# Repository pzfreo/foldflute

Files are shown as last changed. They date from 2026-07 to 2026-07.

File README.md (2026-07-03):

# foldflute

Folded low-D whistle design notes and tooling.

## MCP Setup

This project uses `build123d-mcp` as an AI/MCP server via `uv tool run`; it is
not vendored or tracked as a submodule.

Project-scoped MCP config lives in `.mcp.json` and runs:

```sh
uv tool run --python 3.12 \
  --with openwind \
  --with scipy \
  build123d-mcp@latest \
  --allow-imports openwind,scipy,numpy
```

Openwind and SciPy are included for the acoustic helper workflow described in
`SPEC.md`.

## Layout

- `spec/` — InstrumentSpec JSONC documents (seed spec from SPEC.md §5)
- `foldflute/prelude.py` — acoustic engine, hole optimizer, bend corrections,
  fold-path solver; written to run inside the build123d-mcp `execute()`
  sandbox (load the spec host-side, inject as a dict)
- `scripts/` — parametric CAD builds for the solved designs + raw session log
- `reports/` — REPORT.md (first end-to-end run), solved specs, renders
- `artifacts/` — gated STL/STEP exports (M1 straight, M2 folded)

See `reports/REPORT.md` for the current design state: both M1 (straight) and
M2 (folded foot U-bend) are solved and export print-ready parts; the low A
hole layout is formally infeasible and was relaxed per the spec policy.

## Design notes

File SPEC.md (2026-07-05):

# foldflute - Folded Low-D Whistle Designer

**Project specification - draft v0.3 - 2026-07-03**  
**Owner:** Paul Fremantle

## 1. Overview

foldflute is a single-user desktop toolchain for designing a **folded-bore low D
tin whistle body** that:

- sounds as a low D whistle, with D4 as the fundamental;
- uses **standard six-hole tin whistle fingerings**;
- reuses an existing, known-good whistle headjoint for the windway, window, blade,
  and voicing-critical geometry;
- has the **physical length and approximate finger-hole layout of a low A
  whistle body** supplied by the user.

The bore is folded so that acoustic hole positions along the air column can land
near low A-style exterior finger positions. The acoustic target remains low D;
"low A body size" means physical length and hand layout, not a low A pitch
target.

An LLM orchestrates the design loop through `build123d-mcp` as the primary CAD
workbench: it builds geometry incrementally, renders views, measures dimensions,
checks clearances, compares shape revisions, exports artifacts, and runs
printability analysis. Deterministic solvers own the acoustically critical
numbers: bore length, tonehole positions, tonehole diameters, bend corrections,
chimney lengths, and printability checks.

**Core architectural insight:** the passive pitch model depends on the 1D air
column: bore radius vs. acoustic arc length, side-hole geometry, radiation
conditions, and boundary corrections. The exterior 3D body shape is mostly
acoustically free, provided the CAD-derived chimney depths and bend corrections
are fed back into the acoustic model.

## 1a. Requirement amendment — v0.4 (owner, 2026-07-05)

The low A physical layout goals are **withdrawn**. `physical_layout`
hole-position targets and the low A body-length target no longer constrain
the design. The binding ergonomic requirement is:

- **Adjacent holes within each hand are <= 29.0 mm centre to centre**
  (h1-h2, h2-h3 for the left hand; h4-h5, h5-h6 for the right hand).
- The fipple-to-left-hand distance and the left-hand-to-right-hand distance
  are unconstrained.

Consequences: G4 and the fold-path/layout machinery become optional
(compactness may still motivate folding, but nothing requires it); the
between-hands gap floats to whatever acoustics prefers; body length floats.

## 2. Goals

- G1. Produce a low D whistle body for an existing fixed headjoint.
- G2. Preserve standard six-hole tin whistle fingerings for the D major scale.
- G3. Predict resonance tuning before printing, accurate enough that one
  calibration print should suffice: relative tuning within +/-15 cents before
  calibration and +/-10 cents after one calibration iteration.
- G4. Fold the bore so acoustic hole positions map as closely as possible to a
  user-supplied low A physical layout: overall body length and approximate
  exterior hole/finger positions.
- G5. Wrap the air column in a printable body, with verified wall thickness,
  clearances, drainage, split-shell features, Augura printability analysis, and
  STL export.
- G6. Keep the full loop drivable by an LLM through `build123d-mcp`, using MCP
  tools for normal CAD iteration as well as final verification, while enforcing
  invariants in deterministic helper code.

## 3. Non-goals

- **Headjoint or voicing design.** Windway height, window length, blade geometry,
  chamfers, ramp shape, and mouthpiece ergonomics are copied from the existing
  headjoint and are not optimized.
- **Changing whistle fingering semantics.** v1 targets the standard D whistle
  six-hole diatonic chart. Chromatic half-holing and alternate cross-fingerings
  may be recorded later, but they are not optimized in v1.
- **Transverse flutes or reed instruments.** This project is for fipple whistles.
- **Sound synthesis or playability simulation.** We predict passive resonances,
  not tone, chiff, breath curve, or response.
- **Hosted, multi-user, or cloud service concerns.** This is a local desktop
  workflow.

## 4. System Architecture

```
                 +------------------------------+
                 | InstrumentSpec (JSONC)       |  single source of truth
                 +------+-----------+-----------+
                        |           |
          unrolled 1D   |           |  folded centerline + body params
                        v           v
      +----------------------+   +--------------------------+
      | Acoustic engine       |   | Geometry engine           |
      | (openwind helpers in  |   | (build123d via MCP)       |
      |  the CAD session)     |   |                          |
      | - impedance minima    |   | - folded bore sweep       |
      | - cents per fingering |   | - headjoint interface     |
      | - hole optimizer      |   | - tonehole chimneys       |
      | - bend corrections    |   | - shell split/export      |
      +----------+-----------+   | - clearance checks        |
                 |               | - Augura printability     |
                 |               +------------+-------------+
                 | measured chimney depths                 |
                 v                                         v
      +----------------------+   +--------------------------+
      | Fold-path solver      |   | Calibration protocol      |
      | (scipy constraints    |   | (print -> tuner -> fit    |
      |  + low A layout fit)  |   |  correction -> reprint)   |
      +----------+-----------+   +--------------------------+
                 ^
                 |
        +--------+---------+
        | LLM + human      | proposes topology/body shape,
        +------------------+ reads cents tables, drives iteration
```

### Division of Labour

| Concern | Owner |
|---|---|
| Headjoint/windway/voicing geometry | Existing physical headjoint |
| Standard whistle fingering chart | Spec, fixed in v1 |
| Hole positions, diameters, acoustic corrections | Acoustic optimizer |
| Fold path meeting low A length and finger layout | Fold-path solver |
| Exterior body aesthetics and fold topology choices | LLM + human, iterated in build123d-mcp |
| Incremental CAD modeling, measuring, rendering, export | LLM using build123d-mcp |
| Chimney depths, clearances, split shell, STL | Geometry engine through build123d-mcp |
| Final say on tuning and speaking quality | Human with tuner |

## 5. Data Model - `InstrumentSpec`

One JSONC document, with a Python dataclass mirror. All spec lengths are in
millimetres unless the field name says otherwise. Frequencies are in Hz. The
Openwind adapter converts to SI units at the boundary.

The acoustic arc-length origin is the headjoint window datum. The printable body
usually starts downstream at the headjoint socket. Therefore the full acoustic
bore length is:

```
headjoint.window_to_body_socket + body_centerline.arc_length
```

### Example Seed Spec

This example is intentionally a seed, not a final solved instrument. The user
must measure the existing headjoint and the low A reference body length/hole
layout before M1.

```jsonc
{
  "name": "low-d-folded-whistle-v1",
  "target": {
    "instrument": "low_d_tin_whistle",
    "fundamental": "D4",
    "fundamental_hz": 293.66,
    "pitch_standard_hz": 440.0,
    "temperament": "equal",
    "required_notes": [
      "D4", "E4", "F#4", "G4", "A4", "B4", "C#5", "D5",
      "E5", "F#5", "G5", "A5", "B5", "C#6", "D6"
    ]
  },

  "headjoint": {
    "reference": "reference-headjoints/user-low-d-headjoint-v1.step",
    "fixed": true,
    "acoustic_origin": "window_center",
    "measurements_confirmed": true,
    "tube_outer_diameter": 25.0,
    "tube_inner_diameter": 22.0,
    "tube_inner_radius": 11.0,
    "window_to_tube_end": 120.0,
    "sleeve_extension_beyond_tube_end": 56.0,
    "sleeve_end_from_window": 176.0,
    "sleeve_inner_diameter": 25.0,
    "sleeve_outer_diameter": 28.6,
    "sleeve_fit_clearance_radial": 0.1,
    "sleeve_fit_clearance_diametral": 0.2,
    "printed_body_mating_outer_diameter": 24.8,
    "body_connection": "printed_body_outer_diameter_slips_into_25mm_id_sleeve",
    "window_to_body_socket": 120.0,
    "socket_outer_diameter": 25.0,
    "socket_inner_radius": 11.0,
    "socket_depth": null,
    "nominal_insertion_depth": null,
    "effective_length_correction": 0.0,
    "notes": "Measured from the existing physical headjoint. The printed body acoustic start is at the 120 mm tube end; the 56 mm sleeve is mechanical overlap/retention rather than extra acoustic bore. CAD must not modify voicing geometry."
  },

  "bore": {
    "profile": [
      [0.0, 11.0],
      [120.0, 11.0],
      [590.0, 11.0]
    ],
    "cross_section": "circular",
    "prototype_bore_choice": "cylindrical",
    "body_start_arc": 120.0
  },

  "centerline": {
    "description": "Folded path for the printable body only. It starts at body_start_arc.",
    "segments": [
      {"type": "straight", "length": 172.168},
      {"type": "bend", "angle_deg": 180.0, "radius": 40.0},
      {"type": "straight", "length": 172.168}
    ]
  },

  "holes": [
    {
      "id": "h1",
      "label": "top",
      "finger": "L1",
      "position": null,
      "position_seed": 275.0,
      "diameter": null,
      "diameter_seed": 8.0,
      "position_bounds": [210.0, 340.0],
      "diameter_bounds": [5.5, 11.5],
      "chimney_height_estimate": 3.0,
      "chimney_height_measured": null,
      "exit_normal": [0.0, 0.0, 1.0]
    },
    {
      "id": "h2",
      "label": "second",
      "finger": "L2",
      "position": null,
      "position_seed": 325.0,
      "diameter": null,
      "diameter_seed": 8.0,
      "position_bounds": [260.0, 390.0],
      "diameter_bounds": [5.5, 11.5],
      "chimney_height_estimate": 3.0,
      "chimney_height_measured": null,
      "exit_normal": [0.0, 0.0, 1.0]
    },
    {
      "id": "h3",
      "label": "third",
      "finger": "L3",
      "position": null,
      "position_seed": 380.0,
      "diameter": null,
      "diameter_seed": 8.0,
      "position_bounds": [310.0, 445.0],
      "diameter_bounds": [5.5, 11.5],
      "chimney_height_estimate": 3.0,
      "chimney_height_measured": null,
      "exit_normal": [0.0, 0.0, 1.0]
    },
    {
      "id": "h4",
      "label": "fourth",
      "finger": "R1",
      "position": null,
      "position_seed": 425.0,
      "diameter": null,
      "diameter_seed": 8.0,
      "position_bounds": [360.0, 500.0],
      "diameter_bounds": [5.5, 12.0],
      "chimney_height_estimate": 3.0,
      "chimney_height_measured": null,
      "exit_normal": [0.0, 0.0, 1.0]
    },
    {
      "id": "h5",
      "label": "fifth",
      "finger": "R2",
      "position": null,
      "position_seed": 475.0,
      "diameter": null,
      "diameter_seed": 8.5,
      "position_bounds": [405.0, 545.0],
      "diameter_bounds": [5.5, 12.5],
      "chimney_height_estimate": 3.0,
      "chimney_height_measured": null,
      "exit_normal": [0.0, 0.0, 1.0]
    },
    {
      "id": "h6",
      "label": "bottom",
      "finger": "R3",
      "position": null,
      "position_seed": 525.0,
      "diameter": null,
      "diameter_seed": 9.0,
      "position_bounds": [455.0, 575.0],
      "diameter_bounds": [5.5, 13.0],
      "chimney_height_estimate": 3.0,
      "chimney_height_measured": null,
      "exit_normal": [0.0, 0.0, 1.0]
    }
  ],

  "fingering_scope": "standard six-hole tin-whistle diatonic fingerings, sounding D -> D' -> D''",
  "fingerings": [
    {"note": "D4",  "register": 1, "holes": {"h1": "closed", "h2": "closed", "h3": "closed", "h4": "closed", "h5": "closed", "h6": "closed"}},
    {"note": "E4",  "register": 1, "holes": {"h1": "closed", "h2": "closed", "h3": "closed", "h4": "closed", "h5": "closed", "h6": "open"}},
    {"note": "F#4", "register": 1, "holes": {"h1": "closed", "h2": "closed", "h3": "closed", "h4": "closed", "h5": "open",   "h6": "open"}},
    {"note": "G4",  "register": 1, "holes": {"h1": "closed", "h2": "closed", "h3": "closed", "h4": "open",   "h5": "open",   "h6": "open"}},
    {"note": "A4",  "register": 1, "holes": {"h1": "closed", "h2": "closed", "h3": "open",   "h4": "open",   "h5": "open",   "h6": "open"}},
    {"note": "B4",  "register": 1, "holes": {"h1": "closed", "h2": "open",   "h3": "open",   "h4": "open",   "h5": "open",   "h6": "open"}},
    {"note": "C#5", "register": 1, "holes": {"h1": "open",   "h2": "open",   "h3": "open",   "h4": "open",   "h5": "open",   "h6": "open"}},
    {"note": "D5",  "register": 2, "holes": {"h1": "closed", "h2": "closed", "h3": "closed", "h4": "closed", "h5": "closed", "h6": "closed"}},
    {"note": "E5",  "register": 2, "holes": {"h1": "closed", "h2": "closed", "h3": "closed", "h4": "closed", "h5": "closed", "h6": "open"}},
    {"note": "F#5", "register": 2, "holes": {"h1": "closed", "h2": "closed", "h3": "closed", "h4": "closed", "h5": "open",   "h6": "open"}},
    {"note": "G5",  "register": 2, "holes": {"h1": "closed", "h2": "closed", "h3": "closed", "h4": "open",   "h5": "open",   "h6": "open"}},
    {"note": "A5",  "register": 2, "holes": {"h1": "closed", "h2": "closed", "h3": "open",   "h4": "open",   "h5": "open",   "h6": "open"}},
    {"note": "B5",  "register": 2, "holes": {"h1": "closed", "h2": "open",   "h3": "open",   "h4": "open",   "h5": "open",   "h6": "open"}},
    {"note": "C#6", "register": 2, "holes": {"h1": "open",   "h2": "open",   "h3": "open",   "h4": "open",   "h5": "open",   "h6": "open"}},
    {"note": "D6",  "register": 3, "holes": {"h1": "closed", "h2": "closed", "h3": "closed", "h4": "closed", "h5": "closed", "h6": "closed"}}
  ],

  "physical_layout": {
    "reference": "mk-pro-a-web-derived",
    "source_url": "https://mkwhistles.com/products/mk-pro-low-a-whistle",
    "scale_drawing_url": "https://mkwhistles.com/cdn/shop/files/Pro_A_Scaling_Drawing_v2_7549fd57-1002-4cb1-be67-190358c345fa.pdf",
    "source_confidence": "approximate; derived from published scale drawing using its 20 mm calibration square",
    "meaning": "Physical A whistle body length and approximate finger-hole positions only; acoustics remain low D.",
    "coordinate_system": "x from body socket toward foot, y lateral, z outward from nominal front surface",
    "overall_reference_length": 386.0,
    "body_length": 286.4,
    "body_length_tolerance": 10.0,
    "non_acoustic_tail_allowed": false,
    "length_conflict_policy": "relax_visual_length",
    "max_width": null,
    "max_depth": null,
    "hole_centers_from_socket": {
      "h1": 91.3,
      "h2": 116.8,
      "h3": 143.3,
      "h4": 177.3,
      "h5": 197.3,
      "h6": 230.8
    },
    "hole_position_tolerance": 8.0
  },

  "ergonomics": {
    "finger_template_source": "measured_low_a_body_layout",
    "finger_template": {
      "h1": {"target_xyz": null, "surface_normal": [0.0, 0.0, 1.0], "tolerance": 4.0},
      "h2": {"target_xyz": null, "surface_normal": [0.0, 0.0, 1.0], "tolerance": 4.0},
      "h3": {"target_xyz": null, "surface_normal": [0.0, 0.0, 1.0], "tolerance": 4.0},
      "h4": {"target_xyz": null, "surface_normal": [0.0, 0.0, 1.0], "tolerance": 4.0},
      "h5": {"target_xyz": null, "surface_normal": [0.0, 0.0, 1.0], "tolerance": 4.0},
      "h6": {"target_xyz": null, "surface_normal": [0.0, 0.0, 1.0], "tolerance": 4.0}
    }
  },

  "body": {
    "style_prompt": "low A-sized folded low D whistle body",
    "min_wall": 2.0,
    "shell_split_plane": "bore_plane",
    "split_strategy": "design_split_from_start_with_single_canonical_solid",
    "shell_join": "glued_centerline_seam",
    "gasket": false,
    "alignment_features": true
  },

  "fabrication": {
    "process": "FDM",
    "material": "PETG",
    "print_bed": [256.0, 256.0],
    "max_exported_part_footprint": [250.0, 250.0],
    "layer_orientation": "split halves printed from the centreline split layout, subject to CAD printability checks",
    "shell_closure": "glued_down_centreline",
    "gasket_material": null,
    "headjoint_fit": "push_fit_printed_spigot_into_25mm_id_sleeve",
    "fallback_headjoint_seal": "waxed_thread_wrap_if_push_fit_leaks_or_slips",
    "printability": {
      "mcp_tool": "build123d-mcp.analyze_printability",
      "backend": "pzfreo/augura",
      "analysis_type": "BREP-exact FDM printability",
      "run_on": ["left_shell", "right_shell"],
      "build_volume": [256.0, 256.0, null],
      "bed_fit_margin": 3.0,
      "required_checks": [
        "watertight_manifold",
        "overhangs",
        "thin_walls",
        "minimum_vertical_feature",
        "tip_over_risk",
        "brim_or_raft_need",
        "bed_fit"
      ],
      "support_policy": "prefer redesign/orientation changes over supports inside toneholes, bore, socket, or glue lands"
    }
  },

  "calibration": {
    "temperature_c": 20.0,
    "global_length_correction": 0.0,
    "headjoint_effective_length_correction": 0.0,
    "hole_radius_corrections": {},
    "chimney_corrections": {},
    "observed_fingering_residuals_cents": {}
  }
}
```

### Invariants

- `bore.body_start_arc == headjoint.window_to_body_socket`.
- `centerline.arc_length == bore.profile[-1][0] - bore.body_start_arc` within
  0.25 mm. Bend segment arc length is `abs(angle_rad) * radius`.
- A loaded seed spec may have `holes[].position == null` and
  `holes[].diameter == null`; an optimized spec must not.
- Every optimized hole position must be greater than `bore.body_start_arc` and
  less than the final bore arc length.
- `chimney_height_estimate` may be used only before the first CAD build.
  `chimney_height_measured` must be written back from the actual CAD body before
  convergence is accepted.
- `fingerings` is the source of truth for which holes are open or closed for a
  target note. The LLM does not infer fingering masks from note names.
- The headjoint reference geometry is immutable. CAD tools may model sockets,
  adapters, or mating surfaces, but must not modify windway/window/blade
  geometry.
- `physical_layout` is a low A visual/ergonomic reference only. It must never
  change the target pitch from D4.
- A hole target is geometrically reachable only if the distance from the body
  socket to the target point is less than or equal to that hole's available
  acoustic body arc length, within tolerance:
  `distance(socket, target_xyz) <= hole.position - bore.body_start_arc + tolerance`.
  A fold can make an acoustic path longer than the straight-line distance, but it
  cannot make a point farther away than the arc length available to it.
- `physical_layout.non_acoustic_tail_allowed == false` for this draft. If low A
  visual length conflicts with low D acoustic reach, relax the visual length
  rather than adding a non-acoustic tail.

## 6. Acoustic Engine

Openwind runs in the same Python session as the build123d MCP work so the spec,
CAD-derived chimney depths, and acoustic helpers share one namespace. Use the
project `.mcp.json` to launch `build123d-mcp` via `uv tool run`. The effective
command should be equivalent to:

```
uv tool run --python 3.12 \
  --with openwind \
  --with scipy \
  build123d-mcp@latest \
  --allow-imports openwind,scipy,numpy
```

At session start, call the MCP `version` tool and confirm `build123d-mcp` and
`augura` are listed, then call `health_check`. Augura is the printability backend
used by `build123d-mcp.analyze_printability`; do not replace that gate with a
visual inspection or slicer screenshot.

If Openwind's transitive imports are blocked by the sandbox, use an OS-level
sandbox or local trusted environment and relax the Python import allowlist there.
Do not vendor Openwind into build123d-mcp.

### 6.1 LLM build123d-mcp Workflow

The LLM must use `build123d-mcp` as the normal CAD workbench, not only as a final
export tool. The expected loop for geometry work is:

1. Start each design session with `version`, `health_check`, and `session_state`.
   Confirm `build123d-mcp`, `augura`, and required CAD dependencies are available.
2. Build geometry incrementally with `execute`, keeping stable named parameters
   for all important dimensions: bore radius, bend radius, sleeve fit, wall
   thickness, split-plane offsets, glue-land dimensions, and print-bed limits.
3. Register important shapes with `show(..., name)`. At minimum use names for
   `air_solid`, `body_solid`, `left_shell`, `right_shell`, `headjoint_reference`
   or `headjoint_socket`, and each diagnostic clearance body if created.
4. After every meaningful boolean or sweep, call `measure` before relying on a
   render. Numeric checks are the first proof that the model changed correctly.
5. Use `render_view` for human and LLM visual review after `measure` confirms the
   object is plausible. Use clip planes to inspect bore continuity, toneholes,
   glue lands, and socket geometry.
6. Use `clearance`, `cross_sections`, `find_holes`, `resolve`, and
   `verify_spec` for hard geometric checks: adjacent bore passes, chimneys vs.
   bore passes, shell wall thickness, sleeve fit, and print-bed footprint.
7. Use `save_snapshot` before risky edits and `diff_snapshot` or
   `shape_compare` after changes that should affect only a local region.
8. Use `script` or an equivalent reproducible artifact before export. The final
   STL/STEP files must be reproducible from the saved script plus
   `InstrumentSpec`.
9. Use `export` only after hard checks pass: validity, dimensions, clearances,
   chimney write-back, and Augura printability.

The LLM may propose topology and body-shape changes, but it must not accept an
unmeasured visual impression as proof. Any unresolved MCP error, failed boolean,
unexpected topology count, or failed printability report sends the design back to
the relevant solver/CAD step.

Core functions in the foldflute prelude:

- `load_spec(data) -> InstrumentSpec` validates units, invariants, and the
  fingering chart.
- `to_openwind_geometry(spec, fingering) -> OpenwindInput` converts mm to metres,
  applies headjoint effective-length correction, applies bend corrections, and
  uses measured chimney heights when available.
- `analyze(spec) -> {note: {resonance_hz, cents_vs_target, mode_index}}`
  computes input impedance per fingering and reads the impedance **minima**
  relevant to open-open flute/whistle resonators.
- `optimize_holes(spec) -> spec` solves tonehole positions and diameters for the
  required standard fingerings. It uses Openwind inversion if the constraint set
  is expressible there; otherwise it falls back to scipy optimization around
  `analyze`.
- `apply_calibration(spec, observations) -> spec` fits physical corrections:
  global length, headjoint effective length, hole-radius offsets, and chimney
  offsets. Per-fingering cents residuals are stored for diagnostics, not used as
  the primary fitted variables.

### 6.2 Bend Correction Layer

Openwind has no native 3D bend model. The spec-to-openwind translation applies
published effective-length corrections for bent air columns per bend, as a
function of bend angle and radius/bore ratio. Corrections live in one cited module
so they can be refined against calibration data.

Loss and radiation defaults:

- viscothermal losses on;
- unflanged radiation at open toneholes and the foot;
- room temperature from `spec.calibration.temperature_c`;
- no undercutting model in v1.

## 7. Fold-Path Solver

Input:

- optimized acoustic hole positions and diameters from section 6;
- body centerline topology: fold count, segment order, bend angles, bend radii;
- low A physical layout: body length and approximate hole centers from the socket;
- optional width/depth envelope limits;
- per-hole target exterior point, tolerance, and preferred surface normal.

Output:

- centerline parameters such that each acoustic hole position exits the body
  within tolerance of its assigned low A-style finger target, where reachable;
- hole exit axes that are sealable by the assigned finger and do not intersect
  another bore pass;
- an infeasibility report if the requested topology cannot satisfy the constraints.

Method:

- constrained least squares over segment lengths, bend radii, bend orientations,
  and optional body pose;
- hard rejection for wall, clearance, bend-radius, and physical reachability
  violations;
- soft penalties for finger target error and deviation from preferred normals.

If infeasible, the solver reports which hole/finger/layout constraint failed. The
LLM changes topology or relaxes the low A visual layout; it does not add
non-acoustic tail length or hand-edit acoustic hole positions.

## 8. Geometry Engine and Verification

Build steps, all inside the `build123d-mcp` session and following the section
6.1 workflow:

1. Import or parametrically model the existing headjoint interface. Treat the
   voicing geometry as immutable reference.
2. Build one canonical folded body centerline beginning at `bore.body_start_arc`.
3. Sweep the circular bore along the centerline to create one canonical air solid.
4. Choose the centreline split plane, glue lands, alignment features, and print
   orientation before finalizing the exterior body.
5. Add socket/adapter geometry to mate with the existing headjoint.
6. Generate the exterior body to match the low A reference length and approximate
   hole layout where acoustically reachable.
7. Boolean-subtract the air solid.
8. Cut tonehole chimneys from bore wall to body surface at solved acoustic
   positions and solved exit normals.
9. Write back actual `chimney_height_measured` for every hole.
10. Register the two split shell solids as named MCP objects, conventionally
    `left_shell` and `right_shell`.
11. Run `analyze_printability` on each shell object using the Augura backend and
    store both the plain-text summary and JSON findings with the build artifacts.
12. Export the two split shells and a reproducible build script/artifact only
    after the Augura-backed printability gate passes.

Hard constraints:

- Bend radius >= 1.5x local bore diameter; 2x preferred.
- Folded body approximates the low A physical length within tolerance where
  compatible with low D acoustic reach. If length conflicts, relax visual length;
  do not add a non-acoustic tail in this draft.
- Hole exits are within tolerance of the low A reference positions, unless the
  solver has reported the exact low A location as geometrically unreachable and
  the layout has been relaxed.
- Wall between adjacent bore passes >= `body.min_wall`.
- No tonehole chimney intersects another bore pass.
- Glued centreline seam has continuous bonding land and enough access for clean
  assembly.
- Each exported shell fits inside the 256 mm x 256 mm print bed with margin;
  default maximum footprint is 250 mm x 250 mm.
- Headjoint socket fit has explicit tolerance and insertion stop. The baseline is
  push-fit into the 25 mm ID sleeve; waxed thread wrap is allowed as a fallback
  seal/retention method if the printed fit leaks or slips.
- `build123d-mcp.analyze_printability` passes on every shell, using Augura
  (`pzfreo/augura`) as the printability backend.
- No moisture trap: the lowest interior point in playing orientation drains
  toward an opening, or a drain feature is added.
- Textured or sculptural body details must not thin the wall below `min_wall`.

### 8.1 MCP / Augura Printability Protocol

Printability analysis is an MCP-driven hard gate, not a manual review. For every
candidate geometry:

1. Use `show(shell, "left_shell")` and `show(shell, "right_shell")` in
   `build123d-mcp` so each half is addressable by name.
2. Run `measure` on both shells to confirm non-zero volume, expected bounding
   boxes, and PETG material mass estimates.
3. Run `clearance` and local wall checks for bore-to-bore and chimney-to-bore
   spacing before printability analysis.
4. Run `analyze_printability` on `left_shell` and `right_shell`, with build
   volume set to the 256 mm x 256 mm bed and the default 250 mm x 250 mm maximum
   footprint margin from `spec.fabrication`.
5. Treat any Augura FAIL as design rejection. Preferred fixes are fold topology,
   shell split/orientation, glue land geometry, wall thickness, or local body
   shape changes. Do not accept supports inside the bore, toneholes, socket, or
   glue lands as a primary fix.
6. Store the Augura JSON report beside the STL/STEP exports and include the
   pass/fail summary in the build notes.

Required Augura-backed findings for each shell:

- watertight/manifold solid;
- overhangs compatible with the chosen FDM orientation, or explicitly redesigned;
- thin walls no thinner than `body.min_wall`;
- minimum vertical feature compatible with the intended layer height;
- tip-over/brim/raft risk acceptable for PETG on the selected bed;
- bed fit inside 256 mm x 256 mm, with exported footprint no larger than
  250 mm x 250 mm unless intentionally overridden in the spec.

## 9. LLM Orchestration

The LLM drives the loop through the `build123d-mcp` session. Deterministic
helpers enforce the invariants; the LLM proposes topology, low A layout
interpretation, and body aesthetics. Every geometry iteration should leave MCP
evidence: named session objects, measurements, renders or clipped renders,
clearance checks, snapshots/diffs where useful, and printability reports before
export.

1. Human supplies measured headjoint dimensions or a headjoint CAD/scan.
2. Human supplies the low A reference body length and approximate hole/finger
   positions.
3. LLM drafts `InstrumentSpec` with the standard whistle fingering chart.
4. `optimize_holes` solves acoustic positions and diameters.
5. Fold-path solver places those positions into the low A-style physical layout
   where reachable.
6. Geometry build in `build123d-mcp` writes back measured chimney depths.
7. `analyze_printability` runs through build123d-mcp/Augura on both shell
   objects; rejected geometry returns to topology/body/split design.
8. `analyze` reruns with measured chimney depths and bend corrections.
9. Iterate steps 4-8 until cents table, hole dimensions, chimney depths, and
   Augura printability reports are stable.
10. Render for human review, export STLs, print prototype.

The LLM never hand-adjusts hole positions, hole diameters, or bend corrections.
It changes topology, layout choices, body shape, or targets and reruns the
solvers.

## 10. Calibration Protocol

1. Glue the PETG split shells along the centreline seam and let the adhesive cure.
2. Assemble the existing headjoint with the printed prototype body at the nominal
   insertion depth using the sleeve push fit.
3. Leak-test the glued shell and sleeve joint: block all holes and the foot, then
   check for back-pressure. If the sleeve joint leaks or slips, wrap the mating
   spigot with waxed thread and repeat the leak test.
4. Record each required fingering with a tuner: three trials, moderate breath,
   stable headjoint insertion, temperature noted.
5. Fit physical corrections: global body length, headjoint effective length,
   hole-radius offsets, and chimney offsets.
6. Store observations and fitted corrections in `spec.calibration`.
7. Re-run optimizer and geometry, then reprint if corrections exceed tolerances.

Acceptance after one calibration iteration:

- D4 through D6 standard whistle fingerings within +/-10 cents at moderate breath;
- no hole requires uncomfortable half-covering for a required diatonic note;
- headjoint socket remains airtight and repeatable after disassembly/reassembly.

## 11. Milestones

- **M0 - Headjoint capture.** Measure the existing headjoint: socket dimensions,
  outlet bore radius, window-to-body-socket distance, nominal insertion depth,
  and source/provenance. Exit: reference CAD or parametric interface exists and
  the spec can validate against it.
- **M1 - Straight-body low D validation.** Print a straight low D body for the
  existing headjoint with standard whistle fingerings. Exit: toolchain runs
  end-to-end and relative tuning is within +/-15 cents before calibration.
- **M2 - Folded low D in low A physical layout.** Fold the same acoustic design
  so the exterior length and approximate hole positions follow the measured low A
  reference where reachable. Exit: folded version is within +/-10 cents of the
  straight sibling per required fingering after applying the same calibration.
- **M3 - Ergonomic shell.** Refine the exterior body and finger template for the
  target hand/body size. Exit: all required holes are reachable and sealable,
  and build123d-mcp/Augura printability checks pass for both split shells.
- **M4 - LLM end-to-end.** LLM drives measured brief -> solved spec -> validated
  print files. Exit: one printed folded low D whistle accepted by the human
  player.

## 12. Licensing

- build123d-mcp is Apache-2.0.
- Augura (`pzfreo/augura`) is Apache-2.0 and is used through
  `build123d-mcp.analyze_printability` for BREP-exact FDM printability analysis.
- Openwind is GPLv3 as distributed on PyPI at the time of this draft. Keep it as
  a user-installed optional runtime dependency, for example via `uv tool run
  --with openwind`, and do not make it a bundled dependency of build123d-mcp.
- foldflute imports Openwind in its acoustic helpers. If distributed, license
  foldflute GPL-compatibly or split the Openwind-dependent pieces into a
  separately licensed/private component.
- The existing headjoint CAD/scan must have clear provenance. If it is derived
  from a commercial whistle, keep it private unless permission is explicit.

## 13. Risks and Open Questions

| Risk | Mitigation |
|---|---|
| Existing headjoint effective length is unknown | M0/M1 straight-body calibration before any folded design |
| Headjoint speaks poorly with the solved bore diameter | Match body inlet radius to measured headjoint outlet; test straight body first |
| Fold bend corrections exceed model validity | Keep bend radius >= 2x bore diameter where the layout allows; compare M2 to M1 |
| Deep chimneys from sculptural body detune notes | CAD writes measured chimney heights back before acoustic convergence |
| Split-shell leaks alter tuning | Continuous centreline glue land, alignment features, adhesive cure time, and leak test before tuning measurement |
| Sleeve push fit leaks or slips | Target 24.8 mm printed spigot OD for 25 mm ID sleeve; add waxed thread wrap if needed |
| Augura rejects a shell for overhang, thin wall, bed fit, or tip-over risk | Change split orientation, body shape, glue lands, fold topology, or wall thickness; do not rely on supports inside acoustic or mating features |
| Low A hole targets are farther from the socket than low D acoustic arc length permits | Solver reports infeasible hole/finger pairs; relax the visual layout rather than adding non-acoustic tail length |
| PETG print material, temperature, or moisture drift | Record PETG brand, layer orientation, temperature, and headjoint insertion in calibration |

Open questions:

None for draft v0.3.

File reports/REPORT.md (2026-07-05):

# foldflute first end-to-end run — 2026-07-03

Toolchain run against SPEC.md draft v0.3, driven through `build123d-mcp`
(0.3.62, augura 0.1.5, openwind via `uv tool run`). Deliverables: solved M1
straight and M2 folded designs, gated print files in `artifacts/`, solver
sources in `foldflute/prelude.py`, parametric build scripts in `scripts/`.

## 1. Acoustic model

Openwind 1D FEM, viscothermal losses on, unflanged radiation at holes and
foot, 20 °C, impedance **minima** at the window datum (x=0), headjoint
effective-length correction 0.0 (to be calibrated in M1). Resonances located
by a local geometric frequency grid ±170 cents around each target with
two-stage parabolic refinement — openwind's phase-based
`antiresonance_frequencies()` was unreliable on coarse grids.

Hole positions and bore length are solved by Gauss–Seidel (bore end → D4,
then h6→h1 for E4…C#5) with damped secant steps; register 1 converges to
±0.1 cents in 2–3 sweeps. Register 2 and D6 are *predictions*, controlled by
the diameter choice, which is an input (see §2).

## 2. Diameter scenario study (straight bore)

| scenario | diameters h1..h6 | worst R2 note | h1–h6 span | fold-layout gain |
|---|---|---|---|---|
| S0 seed | 8/8/8/8/8.5/9 | C#6 −97 c | 209 mm | — |
| **S1 big (selected)** | 11/10.5/10/10/10.5/11 | C#6 −26 c | 205 mm | none |
| S2 compression | 11.5/11/10.5/8/7/6.5 | F#5 −37 c | 180 mm | ~25 mm |
| S3 compromise | 11.5/11/10.5/9.5/9/8.5 | C#6 −24 c | 194 mm | ~10 mm |

Selected S1: large holes buy ~70 cents on the top of register 2 (the
open-lattice cutoff moves up); diameter "compression" of the hole span costs
real register-2 accuracy and recovers only ~25 mm of the ~110 mm needed to
reach the low A layout. Passive-model caveat: players overblow the second
register slightly sharp, so the −10…−26 c predictions up high should play
closer than they read.

## 3. Solved designs

Both use S1 diameters, bore Ø22 cylindrical, chimneys 3.30 mm (measured from
the as-built CAD wall and written back per spec; the 3.0 mm estimate shifted
holes by ~1 mm, above the rebuild threshold, so geometry was rebuilt).

**M1 straight**: bore end 571.60 mm from window. Holes (mm from window):
283.6 / 319.3 / 358.9 / 411.1 / 431.9 / 488.3.

**M2 folded**: bore end 574.57 (+2.97 vs M1 — the bend correction re-solve),
bend start 464.90, h6 at 41.8° into the bend. Holes: 283.6 / 319.3 / 358.9 /
411.1 / 431.9 / 489.0.

Model cents (register 1 all ±0.4 c by construction):

| note | D4 | E4 | F#4 | G4 | A4 | B4 | C#5 | D5 | E5 | F#5 | G5 | A5 | B5 | C#6 | D6 |
|---|---|---|---|---|---|---|---|---|---|---|---|---|---|---|---|
| M1 | 0.0 | −0.1 | −0.2 | −0.1 | +0.4 | −0.4 | −0.1 | +7.7 | −2.1 | −9.5 | −6.7 | −17.7 | −23.0 | −25.8 | +13.1 |
| M2−M1 | 0.0 | 0.0 | 0.0 | 0.0 | 0.0 | 0.0 | 0.0 | 0.0 | 0.0 | 0.0 | 0.0 | 0.0 | 0.0 | 0.0 | 0.0 |

M2 matches M1 within 0.03 cents per fingering in-model (the M2 exit
criterion of ±10 c is then a test of the bend-correction model itself once
printed). G3's ±15 c pre-calibration target is met for register 1 + D5/E5/
F#5/G5/D6; A5/B5/C#6 sit at −18…−26 c passive.

## 4. Bend correction (SPEC 6.2)

Toroidal bend, long-wavelength limit, potential (1/r) flow across the
section: inertance ratio bend/straight = (1+√(1−B²))/2 ≈ 1−B²/4, B = bore
radius / bend radius. Same volume ⇒ compliance unchanged ⇒ the bend is
acoustically shorter than its arc by that fraction (pitch rises). Applied as
a piecewise arc-length remapping with κ=1 (velocity-antinode worst case;
κ is the calibration knob). For R=33/bore 11: 2.83% of the 103.7 mm bend arc
= 2.9 mm, ≈ +9 c on D4 — matching the observed +2.97 mm bore-end re-solve.
Refs: Nederveen JASA 104(3):1616 (1998); Félix, Dalmont, Nederveen JASA
131:4164 (2012). (Exact published coefficients are paywalled; the derivation
above is in `foldflute/prelude.py` and is calibration-refinable.)

## 5. Fold-path result — the honest news

With a Ø22 cylindrical bore, a 180° bend needs πR ≥ 104 mm of arc at the
minimum legal radius (1.5×bore Ø = 33 mm):

- between adjacent toneholes: < 57 mm available → impossible;
- above h1 (order-preserving fold-back = 2 bends ≥ 207 mm): ~80 mm of
  straight available below the 56 mm spigot → impossible;
- wholly below h6: ~90 mm of tail → impossible.

**The only legal fold is a foot U-bend with h6 partway into the bend**
(41.8°, 10.5 mm lateral offset — comparable to offset pinky holes on
flutes). Solved fold: R=33, passes 66 mm apart in-plane, visible body 338.5
mm vs low A target 286.4 (+52.1, relaxed per `relax_visual_length`); foot
opening returns up the second pass 6 mm from the bend apex (the low point —
condensate drains to the opening; no drain hole needed).

The low A hole layout itself is **infeasible for any fold topology**: hole
spacing on a single pass equals acoustic spacing (span ~205 mm vs low A's
139.5 mm), and diameter compression tops out ~25 mm (§2). Exterior errors vs
the MK Pro A targets: h1 +17, h2 +27, h3 +40, h4 +58, h5 +59, h6 +81 mm
(tolerance 8 mm). Per SPEC §7 the layout is relaxed rather than hand-editing
acoustics. Datum assumption: `hole_centers_from_socket` measured from where
the body emerges from the sleeve (arc 176); if the datum is the tube end
(arc 120), all errors grow by 56 mm — worth confirming against the MK
drawing.

A 4-pass "S above the holes + foot U" topology could hit the 286 mm length
but needs ≥207 mm folded above h1 where only ~80 mm exists, and would push
h1 above the socket. Options if the low A length matters more than v0.3's
constraints allow: taper/neck the foot bore (relaxes local bend-radius
floor), allow smaller top-fold radii, or accept a ~95 mm-wide 3-tube bundle
with bassoon-style hole ergonomics. Parked for discussion.

## 6. Print architecture and gates

| part | geometry | print | Augura |
|---|---|---|---|
| M2 section_a | x 0–172 + 20 tenon, carries h1, spigot Ø24.8 | vertical, monolithic | 4 warnings¹ |
| M2 left_shell (front) | +z half of section B; carries h2–h6 wholly (seam never crosses a hole) | seam face down | 2 warnings + 3 info |
| M2 right_shell (back) | −z half | seam face down | same |
| M2 alignment_pin ×3 | Ø2.3×4 loose dowels into Ø2.5 recesses in 3 seam bosses | standing | brim advisory |
| M1 section_a | x 0–219 + tenon, h1–h2 | vertical | 5 warnings¹ |
| M1 section_b | x 219–451.6, h3–h6, socket ring | vertical | 3 warnings¹ |

¹ All findings are warnings/info, no failures: (a) tenon/socket stop-ring
ceilings (1.3–2.1 mm ring bridges — left as-is, they are the insertion
stops); (b) tonehole ceilings on vertical prints (4.6–4.8 mm bridges —
routine, ream after printing if sagged); (c) brim recommended on tall
sections (aspect 15–19 — yes, use a brim); (d) 0.2–0.4 mm "thin wall" =
tangential feather edges where hole cylinders exit curved walls, inherent to
drilled toneholes. Augura reported no overhang findings on the Ø22 bore
crowns of the flat-printed shells; treat crown sag as a print-quality watch
item regardless.

Section A is deliberately monolithic (deviation from a whole-body shell
split): the two sealing surfaces — headjoint spigot and joint tenon — stay
seamless and round. Joints: tenon Ø26.0 into socket Ø26.2 (0.2 diametral,
same as the headjoint sleeve fit), 20 mm engagement, shoulder stop, waxed
thread fallback per spec.

All fit checks passed: tenon/socket touching with zero interpenetration,
shells touching on the full seam, air column touching walls with zero
intersection volume. All parts pass the CAD validity gate (watertight
manifold single solids). Footprints ≤ 227×101 mm (bed 256², limit 250²).

## 7. Session evidence

- `reports/solved_designs.json` — full solved specs + cents tables + fold report
- `reports/solver_run_summary.json` — scenario study + provenance
- `reports/m2_*.png` — renders (iso, assembly, clipped)
- `scripts/session_build_log.py` — raw executed-session log (provenance)
- `scripts/build_m*.py` — clean parametric rebuilds
- `artifacts/m1/`, `artifacts/m2/` — STLs (bed-oriented) + canonical STEPs

## 8a. Addendum — convoluted internal bore study (same day)

Clarified intent: the goal was never "shorten with a bend" but a **convoluted
internal bore** so the exterior compresses to low A finger positions. This was
studied quantitatively (`reports/convolution_feasibility.json`, solver code in
`foldflute/prelude.py` v2 section). Result: **infeasible at a Ø22 cylindrical
bore with plain keyless toneholes**, from three directions:

1. **Geometry, shallow chimneys.** Hole span is pitch-set (~205 mm for S1
   diameters; 180 mm at the acoustically-damaged S2 extreme) vs low A's
   139.5 mm. Toroidal detours need ~4R ≈ 132 mm of axial footprint per
   inter-hole gap of 20–34 mm — impossible at any bore radius. Mitred folds
   (Coltman 2006: compensated beveled miter = straight tube −0.32×ID per 90°,
   mode-independent — adopted as the correction model for any internal fold)
   fit *outside* the hole span but cannot compress spacing *within* it.
2. **Stepped deep chimneys.** Holes tapping runs at different depths shift by
   measured −70…−118 cents (−30…−55 mm) — adjacent 25 mm-spaced holes invert
   their physical order. Dead end.
3. **Graded deep chimneys ("ramp bore").** A smooth chimney ramp (10→43 mm,
   no elbows in the hole span) genuinely places all six holes within
   **9 mm of the low A targets** with register 1 in tune — but register 2
   separates catastrophically (F#5 −147 c, G5 −158 c, A5 +128 c): each deep
   tonehole becomes a resonant side branch and the instrument cannot
   overblow. A mild ramp (4→18 mm) is dominated: span only 175 mm, worst
   layout error still +50 mm, register 2 already at −75 c.

The trade frontier (span vs worst register-2 error): 205 mm/−26 c (flat),
175 mm/−75 c (mild ramp), 155 mm/−158 c (full ramp). Register 2 degrades
faster than the layout improves at every point.

**Paths that could still reach low A hand feel** (owner's call, all spec
changes):

- **(a) Ship v1 as-is** — foot-fold M2, proper two-register whistle, length
  339 vs 286 target, hole positions low-D-like.
- **(b) Low A *length*, shifted hand.** Fold ~58 mm of bore into a deep
  gallery above h1 (one mitred sidestep pair fits the 46 mm footprint) plus
  the tail gallery below h6, keeping all chimneys shallow: full 286 mm low A
  body length, S1 register quality, hole block sits ~40 mm higher than the
  low A hand with low-D spacing. Feasible with today's solvers; not yet
  CAD-built.
- **(c) Keys/touch-plates** at low A finger positions actuating pads over
  acoustically-placed holes — the way every large woodwind solves exactly
  this. Printable rocker keys are plausible FDM parts; significant spec/scope
  change (v0.3 non-goal).
- **(d) Narrower/tapered bore study** — second-order for span (hole spacing
  is pitch-set), changes the instrument's voice; not recommended as the
  primary lever.

## 8b. Addendum 2 — M2b built (option b: low A length, shifted hand)

Owner selected path (b). Built and gated (`artifacts/m2b/`,
`reports/m2b_solution.json`): the M1 acoustic solution maps unchanged through
7 Coltman-beveled miter elbows (bevel opening 1.26×ID modeled in CAD; each
elbow −7.04 mm effective). ~58 mm of bore folds into a head gallery
(down 38.8 / across 26 / up 38.8) between the spigot and h1, and the tail
runs down/backward/out the rear face below h6. All chimneys stay 3.3 mm —
register quality is identical to M1 (regression exact; worst R2 −28 c).

- Visible body **288.4 mm** vs low A 286.4 ± 10 ✓. Bbox 344.4×30×67.6.
- Visible holes 58.2/93.9/133.5/185.7/206.5/262.9 → errors vs low A targets
  −33/−23/−10/+8/+9/+32 mm: h3–h5 hit the low A hand, h1/h2 sit high,
  h6 low (span is pitch-set; see 8a).
- Section A (0–156 + tenon): monolithic vertical print — spigot and tenon
  stay round; contains galleries + h1 + h2; gallery legs teardropped
  (r 10.2 + 45° roof, area-compensated) for the vertical print; 45° wedge
  transition behind the head bulge (removed a 1097 mm² support ceiling).
  Section B (156–344.4): left/right shells split on the y=0 bore plane —
  channels face up on the bed, zero bore overhangs; 3 dowel-pin bosses.
- Gates: validity PASS ×4, tenon/socket and shells zero-interpenetration,
  air exactly fills the bore, Augura: shells 1 advisory (0.25 mm feature caps
  layer height), section A warnings only (tenon-root 2 mm ring bridge, h1/h2
  hole ceilings 4.6–4.8 mm, brim, feather edges). One fix applied from an
  Augura tip-over ERROR: the socket collar side lip made the shell rock —
  collar now flush at width 30 (socket side walls 1.9 mm, 0.1 under min_wall,
  accepted at a reinforced band).
- Condensate collects in the head gallery across-run; both galleries drain
  through the rear foot opening when the instrument is stood upright.
  Swab access via the A/B joint. Exterior is a plain prism — sculpting for
  hand comfort is deliberately left for after the calibration print.

## 8. Open items / assumptions to confirm

1. **Headjoint effective length 0.0** — M1 exists to calibrate this; expect
   all notes to shift together on the first print (fit with
   `global_length_correction` + `headjoint_effective_length_correction`).
2. Low A datum ambiguity (§5).
3. Insertion depth assumed full (56 mm): body acoustic start = tube end.
4. Register-2 passive flatness (A5/B5/C#6): revisit after M1 tuner data;
   options are bigger h1/h2, chimney thinning at the top holes, or accepting
   player compensation.
5. `H6_MAX_BEND_ANGLE_DEG = 50°` is an ergonomic judgment — verify R3 can
   seal a hole offset 10.5 mm laterally on the printed prototype.
6. Bend-correction κ=1.0 — M2-vs-M1 tuner comparison calibrates it.
7. `apply_calibration()` (fitting corrections from tuner observations) is
   not yet implemented — deliberately deferred until M1 data exists.
8. **As-exported FEM gate (owner requirement, do when M2d CAD lands):**
   in addition to the parametric-mirror gate, import the literal exported
   STEP (`m2d_body_canonical.step`) into netgen (`OCCGeometry` on the file),
   classify window/hole-exit/foot faces geometrically, and re-run the
   Helmholtz gate on at least D4/A4/C#5 directly on the shipped artifact.
   Purpose: catch any divergence between solver state, CAD mirror, and the
   actual export before printing.

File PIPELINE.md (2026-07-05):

# foldflute geometry pipeline

One document, one kernel, one CAD path, one gate. Built to remove the failure
mode where geometry was described several times (solver state, ad-hoc JSON,
hand-written FEM reconstruction, hand-built preview) and the acoustic gate ran
on a *reconstruction* rather than the shipped artifact.

## Data flow

```
spec/m2d.json                         canonical document (edit this)
      │
      ▼
foldflute/geometry.py   pure kernel (math+json; imports in every venv)
      │  r_bore · face_plane · hole_exit · manifest · to_openwind · invariants
      ├────────────────────────────┐
      ▼                            ▼
foldflute/solids.py          scripts/fem/gate.py
 (.venv-cad, build123d)        (.venv-fem, ngsolve)
   air.step + body.step          imports air.step + manifest.json,
   + manifest.json               tags faces, 3-D Helmholtz per fingering,
      │                          compares to openwind 1-D from the SAME kernel
      ▼
scripts/regen.py  →  artifacts/m2d/  + invariant checks (fails loud)
```

The kernel is the *only* place geometric numbers are computed. `solids.py` and
`gate.py` both derive from it, so CAD, 1-D acoustics, and 3-D FEM cannot
silently describe different geometry. The FEM meshes the **literal exported
STEP** (not a mirror); `manifest.json`, also kernel-derived, tells it which
face is the window / each hole exit / the foot.

## Commands

```sh
# regenerate all artifacts from the doc + run invariants (build123d venv)
.venv-cad/bin/python scripts/regen.py                # -> artifacts/m2d/, PASS/FAIL

# as-exported acoustic gate on the shipped STEP (ngsolve venv)
.venv-fem/bin/python scripts/fem/gate.py \
    --artifacts artifacts/m2d --spec spec/m2d.json --note all
```

## Invariants (regen, all must PASS before print)

1. **round-trip** — air.step re-imports at volume match 1.00000 (export sane)
2. **analytic tripwire** — CAD air volume within 8% of the kernel's analytic
   integral (catches gross generator failure; currently 0.994)
3. **within-hand gaps** — every constrained hole pair ≤ 29 mm c-c (spec v0.4)
4. **single solid** — body.step is one closed solid (printability precondition)

The gate adds the cross-environment check: **mesh volume vs manifest air
volume** (currently 1.004 — same solid on both sides), then the acoustic
FEM-vs-1D table per fingering.

## Environments

- `.venv-cad` — build123d + openwind + scipy + numpy (solids, 1-D acoustics,
  the solver re-loop)
- `.venv-fem` — ngsolve + openwind + numpy (the gate)
- both import `foldflute/geometry.py` unchanged; the build123d-mcp session is
  now only an interactive inspector (import the STEP to render/measure), not a
  build authority.

## Status / next

The doc currently holds the pre-correction M2d solve. The gate confirms the
pipeline reproduces the earlier reconstruction's differentials (up-bore-tilted
h3/h6 read sharp; down-bore tilts clean; ~+24 c all-closed baseline offset).
Next design step: fit per-hole corrections from `reports/gate_m2d.json`,
re-solve into `spec/m2d.json`, `regen`, gate again — one loop, one truth. Then
the print-part CAD (sections/joint/chamfers) extends `solids.py`.
Known rough edge: the gate's mode picker occasionally mis-selects on all-open
fingerings (C#5); needs a mode-shape (energy-localization) filter.

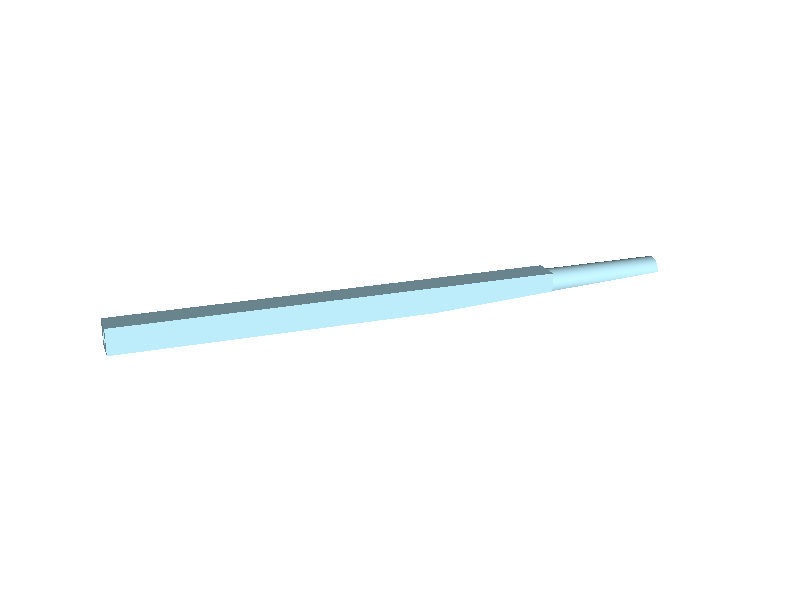
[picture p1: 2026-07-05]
reports/m2d_pipeline_body.png

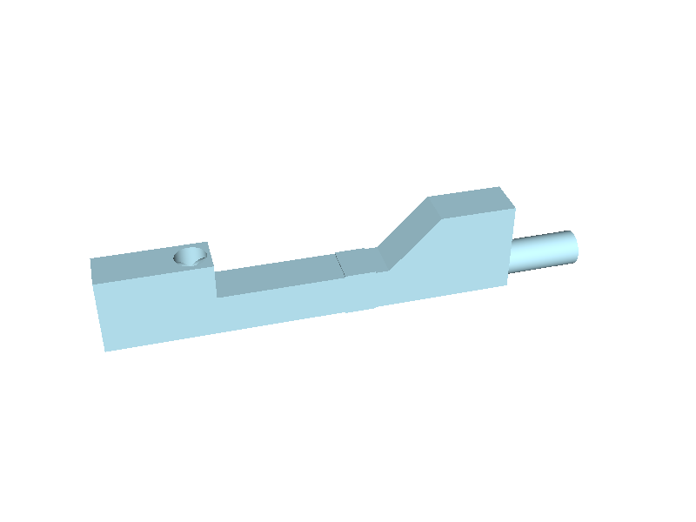
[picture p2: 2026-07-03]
reports/m2b_body_iso.png

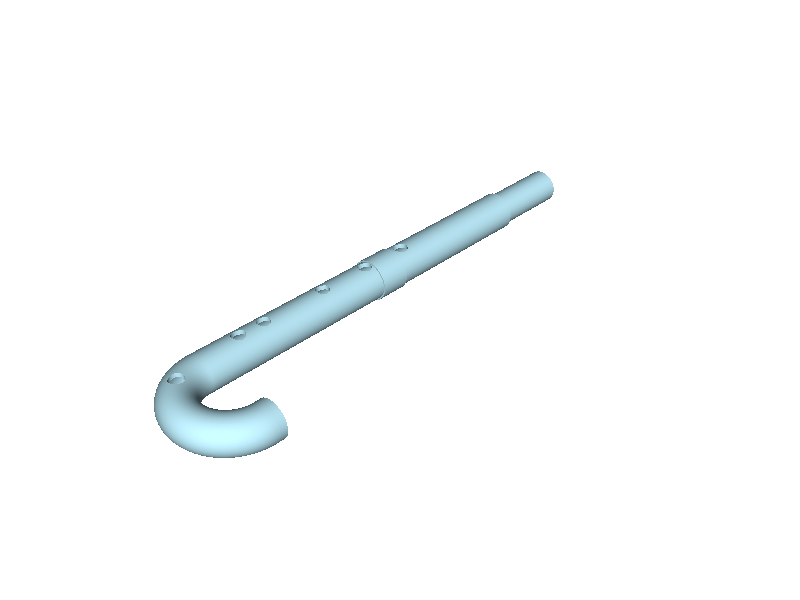
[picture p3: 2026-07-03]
reports/m2_body_iso.png

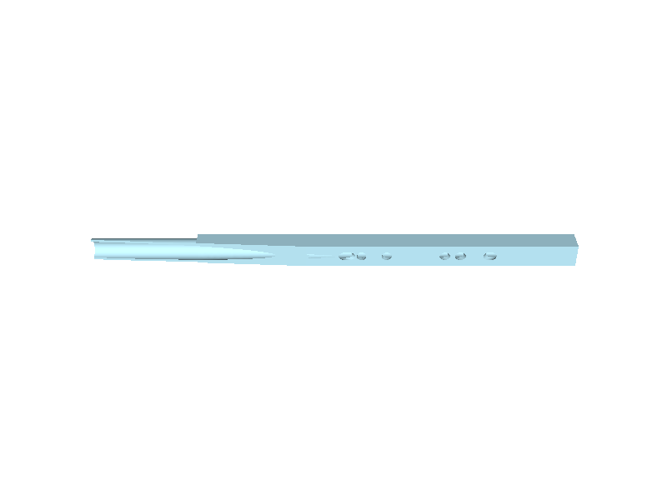
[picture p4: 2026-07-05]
reports/m2d_pipeline_face.png

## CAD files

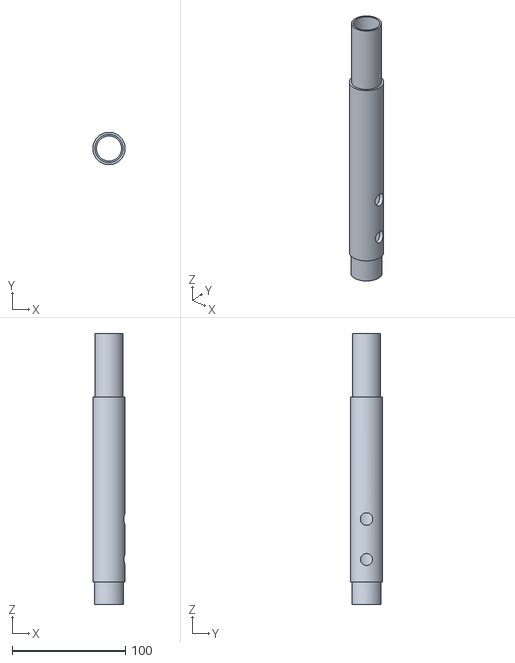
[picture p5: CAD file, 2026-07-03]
artifacts/m1/m1_section_a.stl
28.6 x 28.6 x 239.0

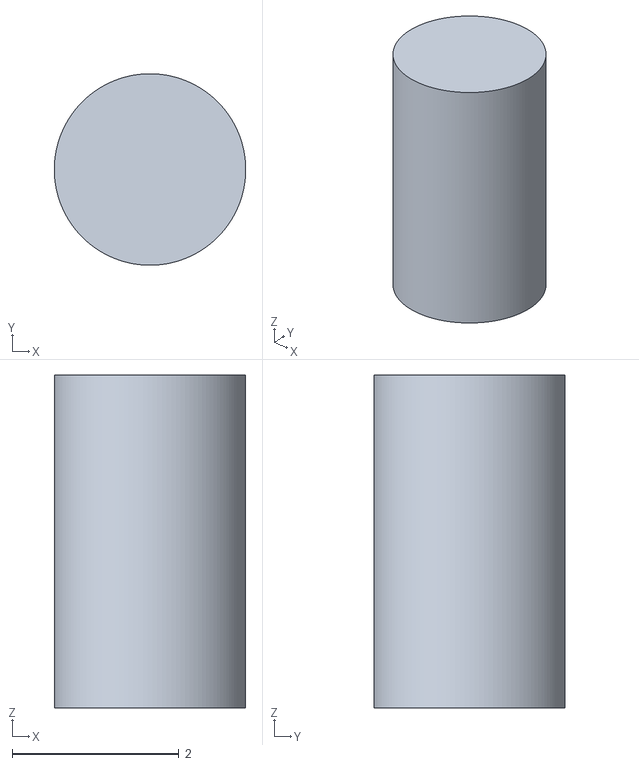
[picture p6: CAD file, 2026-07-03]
artifacts/m2/m2_alignment_pin.stl
2.30 x 2.30 x 4.00

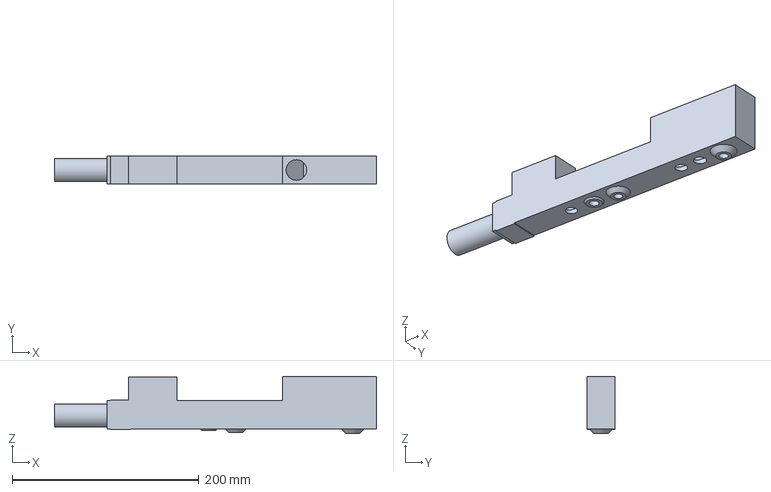
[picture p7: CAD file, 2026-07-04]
artifacts/m2b/m2b_body_canonical.step
344.4 x 30.0 x 61.2 mm

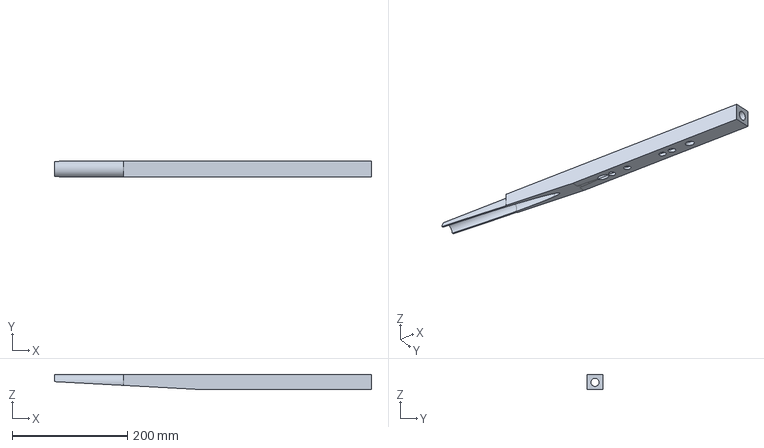
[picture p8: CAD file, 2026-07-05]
artifacts/m2d/body.step
550.5 x 27.0 x 25.8 mm

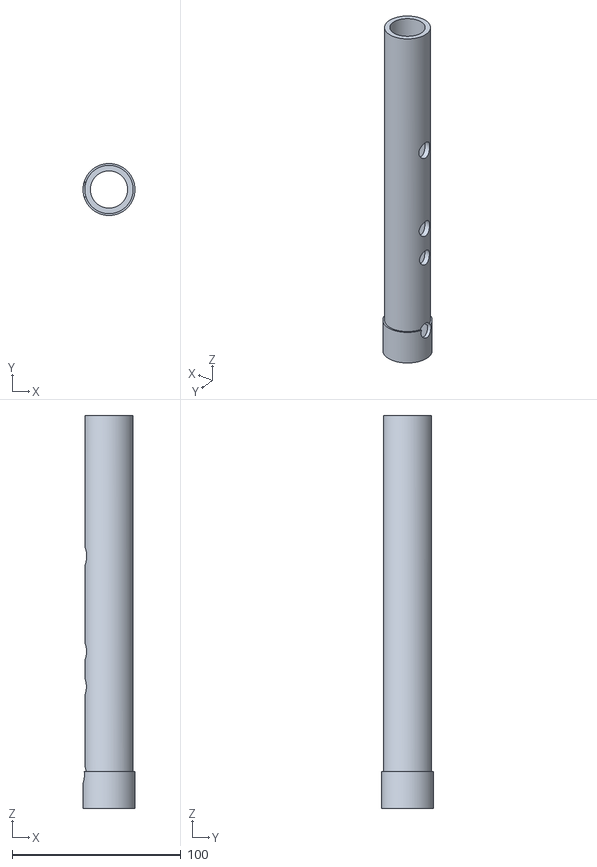
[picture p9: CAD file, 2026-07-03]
artifacts/m1/m1_section_b.stl
30.8 x 30.8 x 232.6

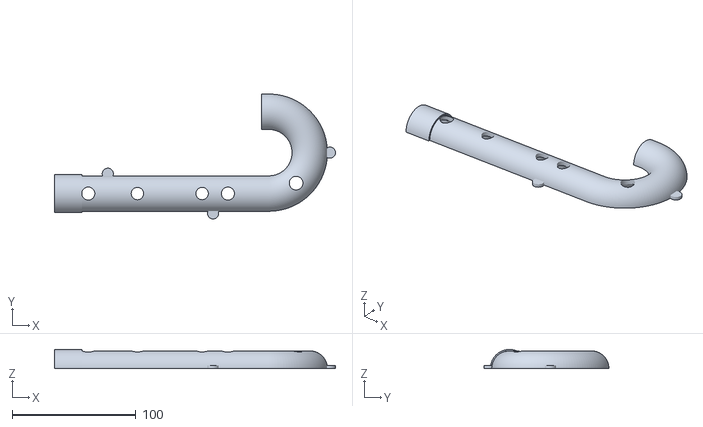
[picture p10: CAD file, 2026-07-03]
artifacts/m2/m2_shell_front.stl
226.7 x 100.8 x 15.4

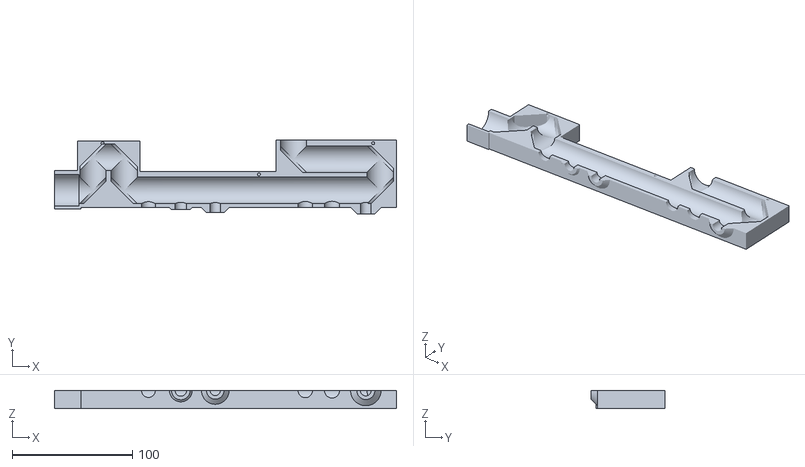
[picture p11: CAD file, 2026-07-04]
artifacts/m2b/m2b_shell_left.stl
284.4 x 61.2 x 15.0

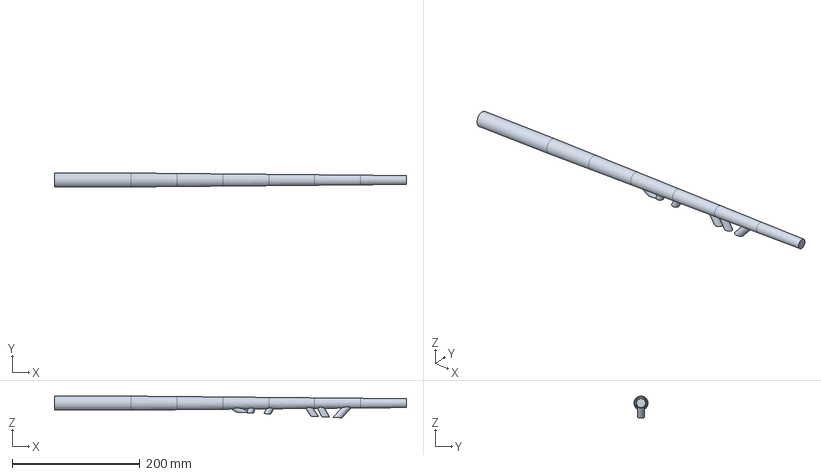
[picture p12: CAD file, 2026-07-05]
artifacts/m2d/air.step
550.5 x 22.0 x 34.1 mm

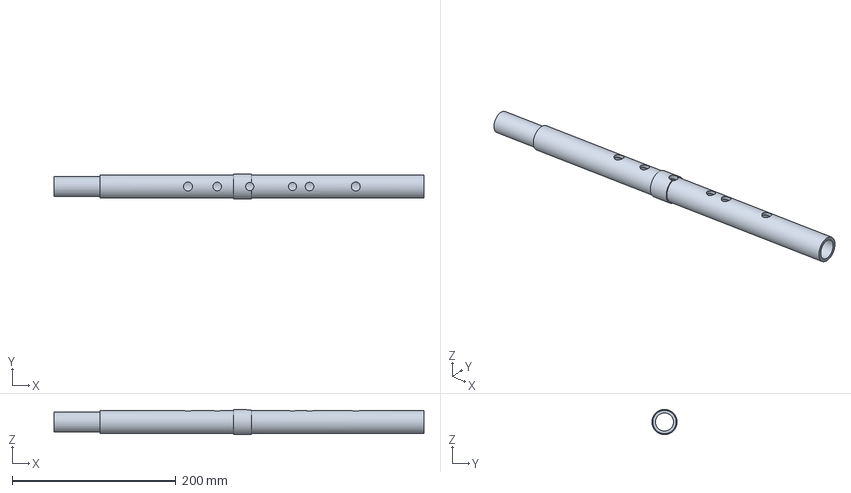
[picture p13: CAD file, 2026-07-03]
artifacts/m1/m1_body_canonical.step
451.6 x 30.8 x 30.8 mm

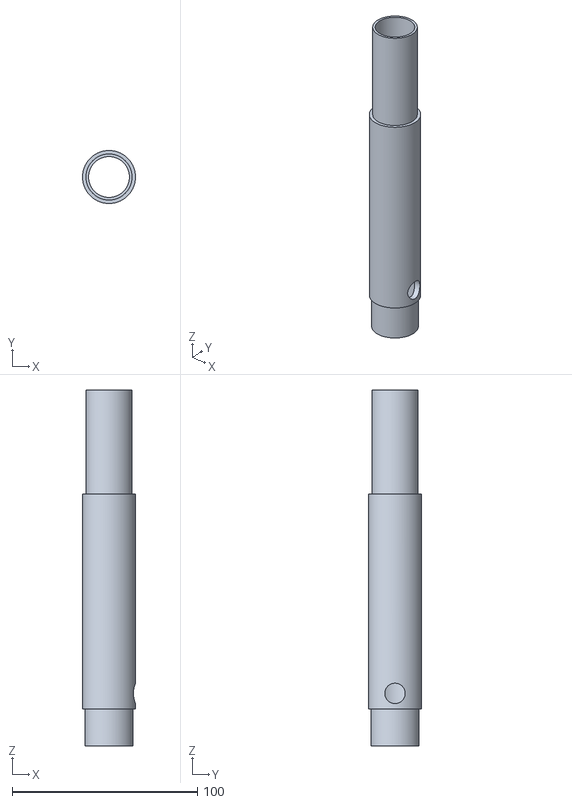
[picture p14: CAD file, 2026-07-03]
artifacts/m2/m2_section_a.stl
28.6 x 28.6 x 192.0

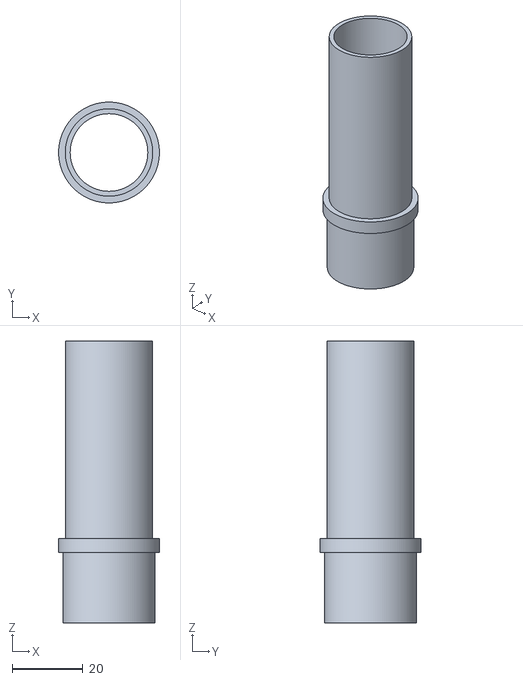
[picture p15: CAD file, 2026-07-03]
artifacts/m2b/m2b_section_a.stl
28.6 x 28.6 x 80.0

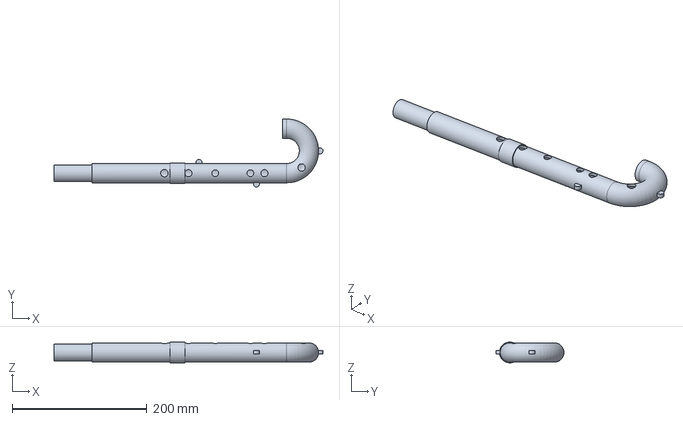
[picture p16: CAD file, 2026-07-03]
artifacts/m2/m2_body_canonical.step
398.7 x 100.8 x 30.8 mm

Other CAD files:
artifacts/m2b/m2b_shell_right.stl
artifacts/m2/m2_shell_back.stl
artifacts/m2b/m2b_alignment_pin.step

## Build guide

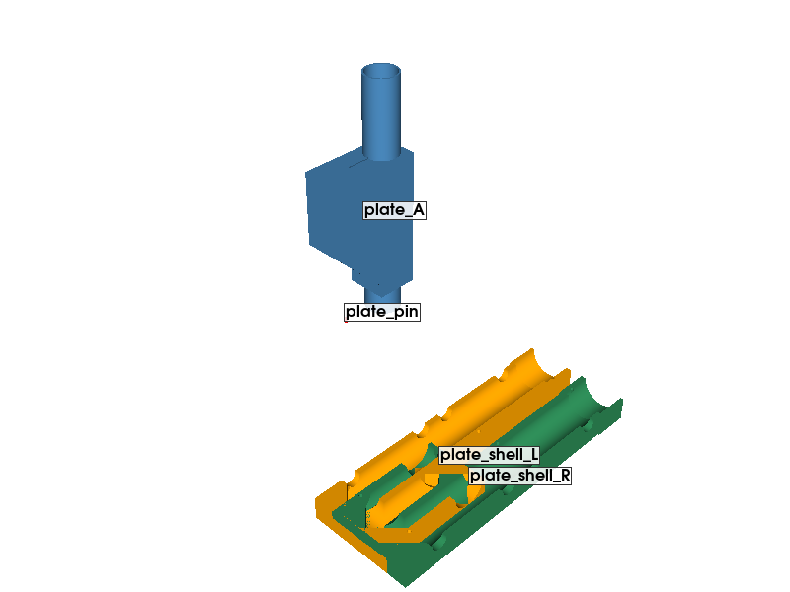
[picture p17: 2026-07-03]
reports/m2b_print_plate.png

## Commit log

2026-07-03 First end-to-end run: solved M1 straight + M2 folded designs with print files
    Implements the SPEC.md v0.3 toolchain and drives it through build123d-mcp:
    - foldflute/prelude.py: openwind adapter (impedance minima at the window
    datum, unflanged radiation, viscothermal losses), Gauss-Seidel hole/bore
    optimizer (register 1 to +/-0.4c), derived+cited toroidal bend correction,
    and the fold-path solver with hard-vs-layout constraint reporting.
    - Diameter scenario study: large holes (11/10.5/10/10/10.5/11) chosen for
    register-2 accuracy; hole-span compression cannot reach the low A layout.
    - Fold finding: with a 22mm cylindrical bore the only spec-legal fold is a
    foot U-bend (R=33) with h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
    [m1_body_canonical.step, m1_section_a.stl, m1_section_b.stl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]
2026-07-03 Convoluted-bore feasibility study: low A finger positions are infeasible at Ø22
    Clarified goal (internal bore convolution to compress the exterior to low A
    finger positions) studied quantitatively with openwind in-session:
    - Adopt Coltman (2006) compensated miter bends as the internal-fold
    correction model: beveled 90-deg miter = straight tube shortened by a
    mode-independent 0.32*ID (prelude v2: elbow_effective_map, analyze_v2).
    - Geometry route: toroidal detours need ~4R (~132mm) per 20-34mm inter-hole
    gap; mitred folds fit outside the hole span but cannot compress spacing
    within it (span is pitch-set at ~205mm vs low A 139.5mm).
    - Stepped deep chimneys: measured -70..-118c shifts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
2026-07-03 M2b: low-A-length body via head/tail bore galleries (option b)
    Maps the M1 acoustic solution unchanged through 7 Coltman-beveled miter
    elbows: ~58mm of bore folds into a head gallery between spigot and h1, and
    the tail exits down/backward through the rear face below h6. All chimneys
    stay 3.3mm, so register quality is identical to M1 (worst R2 -26c).
    Visible body 288.4mm vs low A 286.4+-10; holes h3-h5 land on the low A hand
    (-10/+8/+9mm), h1/h2 high and h6 low as pitch geometry dictates (REPORT 8a).
    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
    [m2b_body_canonical.step, m2b_section_a.stl, m2b_shell_left.stl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]
2026-07-03 Add M2b print-part STEPs and plate render
    [m2b_alignment_pin.step, m2b_section_a_print.step, m2b_shell_left_print.step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]
2026-07-03 M2b rev2: V-profile hole compression + printable section A
    Within-hand finger stretches reduced from 75.3/77.2mm to 63.2/58.2mm
    (low A reference 52/53.5) via a per-hand diameter profile (big top hole,
    small bottom: 11.5/9.5/7.5 | 12/9.5/7.5), solved to +/-0.2c in register 1;
    register 2 cost is moderate (worst -38c vs -26c, table in m2b_rev2.json).
    Section A could not slice: the flat 30x30 prism-to-tenon face cantilevered
    8mm over the round tenon. Replaced with a 45-deg square-to-round loft; the
    A/B joint moved to the wide between-hands gap (x=210). Remaining Augura
    findings are advisories only (4-5mm tonehole bridges, brim, feather edges).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
    [m2b_body_canonical.step, m2b_section_a.stl, m2b_section_a_print.step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]
2026-07-03 M2b rev3: enforce 29mm max within-hand finger gap
    All adjacent within-hand hole gaps now 26.9/28.6/22.2/28.1mm c-c (h3-h4
    between-hands gap 74.9). Achieved with per-hole diameters 11.5/8.5/7.0/12/
    12.5/7.2 plus small chimney pads on h3 (4.2mm) and h6 (4.5mm), solved to
    +/-0.2c in register 1. Register-2 cost concentrated in the top three notes
    (A5 -45, B5 -59, C#6 -58 passive; D5-G5 within -21). As-built CAD verified
    by find_holes: hole diameters and pad chimneys match the model inputs.
    [m2b_body_canonical.step, m2b_section_a.stl, m2b_section_a_print.step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]
2026-07-03 M2b rev4: joint moved above the gallery - section A cannot topple
    The 235mm tenon-standing tower was a dynamic topple risk regardless of
    Augura's static check. The A/B joint moves to x=60: section A is now an
    80mm round connector (spigot + tenon only, aspect 6.5), and the galleries,
    all six holes, and the tail live in the shell pair (284x57mm, prints flat
    with zero bore overhangs - teardrop compensation no longer needed, gallery
    legs are clean circular bore again). Shells need diagonal bed placement
    (~40 deg) on a 256mm bed. Acoustics unchanged (hole positions independent
    of gallery column placement); gallery columns shifted to 92/118 to clear
    the relocated socket.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
    [m2b_body_canonical.step, m2b_section_a.stl, m2b_section_a_print.step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]
2026-07-04 M2b rev5: Carbony-style turret chimneys with larger holes
    Owner's Carbony close-spaced low D confirms the maker practice: same hole
    positions are better achieved with bigger holes under taller chimneys than
    small holes under short ones (same acoustic mass, ~50% more venting area,
    less nonlinear choking at volume). Holes now 11.5/9.5/8.5/12/12.5/9.0 with
    chimneys 3.3/5.0/7.5/3.3/3.3/8.5 (45-deg frustum turrets +1.7/+4.2/+5.2mm
    proud of the face on h2/h3/h6). Positions and 29mm gap set unchanged;
    register 1 within 2c; register 2 unchanged vs rev3 (worst B5 -59 passive).
    As-built verified by find_holes; shells gate clean (advisories only).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
    [m2b_body_canonical.step, m2b_shell_left.stl, m2b_shell_right.stl]
2026-07-04 Add 3D Helmholtz FEM verification (NGSolve) of the rev5 air geometry
    Solves the acoustic eigenproblem on the actual 3D air volume (galleries,
    beveled miter elbows, turret chimneys, hole-crown curvature) plus a block
    of exterior air, p=0 at the window plane and far boundary, fingertip caps
    sealing closed holes. Compares each fingering's resonance with openwind's
    production 1D prediction. Calibration case (plain cylinder) reproduces the
    ideal series to 0.00 cents at maxh=6/p2.
    Early findings: geometry mirror volume-verified against CAD; accidental
    truncated-column run confirmed the Coltman mitre corrections (FEM effective
    length 455mm vs 1D-with-corrections 452mm over 7 elbows).
    Co-Authored-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
2026-07-04 FEM vs 1D comparison table for all 15 fingerings
2026-07-04 M2c periscope first co-solve: FEM-corrected model + angled-chimney layout
    FEM-corrected 1D (matching_volume + 1.6mm open-hole inner correction)
    reproduces the 3D FEM within ~5c across register 1. Angled-chimney co-solve
    reaches all within-hand exit gaps <=29mm with S1 diameters, crown ramp
    5->11mm, angles up to 52 deg, chimney paths 6-16mm. R1 nearly converged
    (worst -10.6c, needs 1-2 more sweeps); R2 still shows the chimney tax
    (F#5 -47, A5 -87 in corrected 1D) - solve needs R2-aware iteration and the
    FEM gate before any CAD.
2026-07-04 M2d Sigo-style tapered serpentine: best acoustics of any compressed design
    Bore taper 22->14mm with a curved bore line (crowns 4->16mm) and angled
    chimneys, solved under the FEM-corrected model: all within-hand exit gaps
    at <=29mm (one 0.2mm nudge pending), register 1 within 2.2c, and register 2
    transformed: A5 -11.8, B5 -9.0, C#6 -21.1 (vs -45/-59/-58 in rev5). The
    taper makes graded deep chimneys affordable ((D/d)^2 correction scaling),
    which is the transferable mechanism behind the Kunath Sigo. D6 sits +49c
    (taper stretches mode 4) - the one casualty. Needs 3D FEM re-gate (the
    1.6mm correction was fitted on cylindrical shallow-chimney geometry) and
    CAD before print.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
2026-07-04 WIP: M2d FEM re-gate - geometry validated, eigen-extraction defect open
    Tapered/curved-bore/angled-chimney FEM domain builds and meshes: piecewise
    conical frustums (Cone angle is RADIANS in netgen.occ - was silently
    wrapping 57x), exact chimney-to-face-plane intersections, protruding stubs
    for col/ext imprinting. Validated: column volume matches analytic (163.7k),
    column-only eigensolve gives a clean mode series (D4-config 297.6/598/901).
    OPEN DEFECT: in the glued col+exterior domain the column modes appear
    truncated (D4 lowest 477.6 vs ~292 expected; C#5 all-open 1168 vs ~540)
    even though regions, volumes, and boundary naming audit correctly, and the
    box's own modes start at ~1576 (Dirichl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
2026-07-05 Fix M2d FEM gate: radiation-pocket architecture + cylindrical control
    Root cause of the dead gate: the box-minus-body exterior is a thin air
    shell with its own dense mode family from ~477Hz that buries the column
    physics (mode-shape probe: 96% of the 477.6Hz mode's energy was exterior).
    Replaced with local radiation pockets at each open exit - pocket cavity
    modes sit >1.9kHz, leaving the band pure column. Closed holes seal by
    omission (no caps). Column-only probes validate the exotic geometry
    (all-open C#5 at 556.7Hz = ideal-ends physics).
    Control anchoring: the same harness on cylindrical rev5 reads a uniform
    +18+-3c pocket-radiation offset. Against that anchor, M2d's D4/C#5 agree
    within ~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
2026-07-05 SPEC v0.4 amendment: within-hand 29mm gaps replace all low A layout goals
    Owner requirement update: low A hole positions and body length withdrawn;
    the binding ergonomic constraint is adjacent within-hand hole gaps <=29mm
    c-c, with fipple-to-LH and LH-to-RH distances free.
2026-07-05 Rewrite FEM gate: column-only with end-correction stub terminations
    Abandon the exterior-air pocket harness (four geometry-leak bugs; its
    cylindrical control never stabilized - see history). New formulation:
    each open exit and the foot are extended by a 0.6133*a unflanged
    end-correction stub terminated p=0, matching openwind's unflanged 1D
    termination physics by construction. FEM-vs-1D differences now isolate
    the interior 3D effects under test (taper, crowns, angles, hole-crown
    curvature). Domain is compact: no Glue, no pockets, fast meshes.
    Acceptance: cylindrical control must sit uniform within a few cents.
2026-07-05 Stub-termination FEM gate results: harness validated, M2d corrections quantified
    Control (cylindrical rev5) is stable and structured; M2d-minus-control
    differentials agree with the independent box-harness run-1 within ~10c on
    nearly every note (cross-harness reproducibility = real geometry physics,
    not artifacts). Verdict: up-bore-tilted chimneys (h3 -41deg, h6 -46deg)
    read +35..+50c sharp of the corrected 1D; down-bore tilts up to +52deg are
    fine; taper-bore baseline +14c. Next: fit per-hole corrections from this
    table, re-solve, confirm with one more gate pass.
2026-07-05 M2d preview STEPs (canonical solve, pre-correction, NOT for print)
    [m2d_PREVIEW_air.step, m2d_PREVIEW_body.step]
2026-07-05 Robust geometry pipeline: canonical doc + pure kernel + single CAD path
    Fixes the workflow fragility (geometry described 4 times, gated on
    reconstructions). New spine:
    - spec/m2d.json: single source of truth for the M2d tapered whistle
    - foldflute/geometry.py: pure kernel (math+json), imports in every env;
    the only place bore radius, face plane, chimney paths, exits, openwind
    inputs, and invariants are computed
    - foldflute/solids.py: build123d in .venv-cad, the one CAD path; exports
    air.step + manifest.json (the FEM's face-tag contract) and body.step
    Kernel reproduces prior geometry (face plane to 4dp, air vol within 0.6%)
    and 1D acoustics exactly; air STEP round-trips at match=1.0000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
2026-07-05 Fix face-cut geometry + document robust pipeline
    Face-cut bugs fixed: (1) wrong side kept (room side, not bore side) - now a
    plane-frame half-space with explicit normal; (2) single tilted face sliced
    the round head bore - face cut now applies only over the hole span, head
    stays full round. Air volume 163712 vs analytic 164702 (ratio 0.994).
    The as-exported FEM gate (scripts/fem/gate.py) now meshes the literal
    air.step and reproduces the prior reconstruction's FEM-vs-1D differentials
    (D4 +24.7, A4 +55.6, E5 +49.3), with mesh-vs-manifest volume 1.004 - same
    solid on both sides. PIPELINE.md documents the doc->kernel->solids->gate flow.
    [air.step, body.step, m2d_PREVIEW_air.step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]
